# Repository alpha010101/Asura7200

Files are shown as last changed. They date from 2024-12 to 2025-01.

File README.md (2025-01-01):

## ASURA7200

###
ATmega4808を使ったマイコン基板で、NXPのPCA9685という16chのPWM制御ICの評価を目的としている。用途はLEDの明るさ制御で、PWMが4096階調であることから、よくある256階調などよりも滑らかな明るさの変化が実現できる。また、PWMのクロックが高速であるためにチラつきが無い。このあたり、実際に見てみれば誰にでも分かるが、256階調や低速クロックによるチラつきのあるものとは光の質が全く違う。

同様のことを旧基板ではTIのTLC5940というICで行っていた。機能としてはPCA9685とそれほど変わらないが、TLC5940がSPIに似た制御であるのに対し、PCA9685は完全に  I2Cでの制御となっており、他のICと信号線を使い回せる点が有り難い。それ以外もPCA9685の方が応用の範囲が広いように思われる。

電源はXHコネクタから入れており、7V~35Vの入力を受け付け、それをMC7805レギュレータで5V/1Aの内部電源に落としている。これは入力に12Vや24Vを入れてLEDの駆動に使うことを前提にしているためである。このように5Vを超える電圧でLEDを駆動するために、LEDのドライバには東芝のDMOS-SINKドライバTBD62083を使用している。  
  
この他にオマケとしてRTC用としてDS1307を載せており、これもI2C制御になる。バッテリーソケットはこれのバックアップ用。

スカスカの基板に見えると思うが、旧基板にサイズやコネクタを合わせたためにこうなった。ゼロから作るならもう少しコンパクトなコネクタを使うと思う。ミスったのは、通電を示すLEDを付けなかったことで、旧基板がそうだったので忘れていた。基板上に1個のってるLEDはNeo-pixelのRGB LEDで、ソフトウェアの動作ステージなどを示す目的で設けられている。

ソフトウェア開発はArduinoを想定。ATmega4808はArduino-nano-everyなどでも使われており、それほどマイナーでは無いものの、流通しているライブラリではATmega4808を想定していない（デフォルトがATmega328)ものもかなりあり注意が必要だった。例としてはArduinoのSketchで用意された割り込みではなく、直接割り込みを操作しているようなライブラリではATmega328とATmega4808の割り込みの仕組みが違うために動作しないものがあった。  
  
設計当初は意識していなかったのだが、ATmega4808は3系統のUARTを使用可能でその後これに助けられたことがあった。

SchematicとPCB\_LayoutはAutodesk-Eagleの無償版を使用し、elecrowで製造することを想定したガーバーを作成している

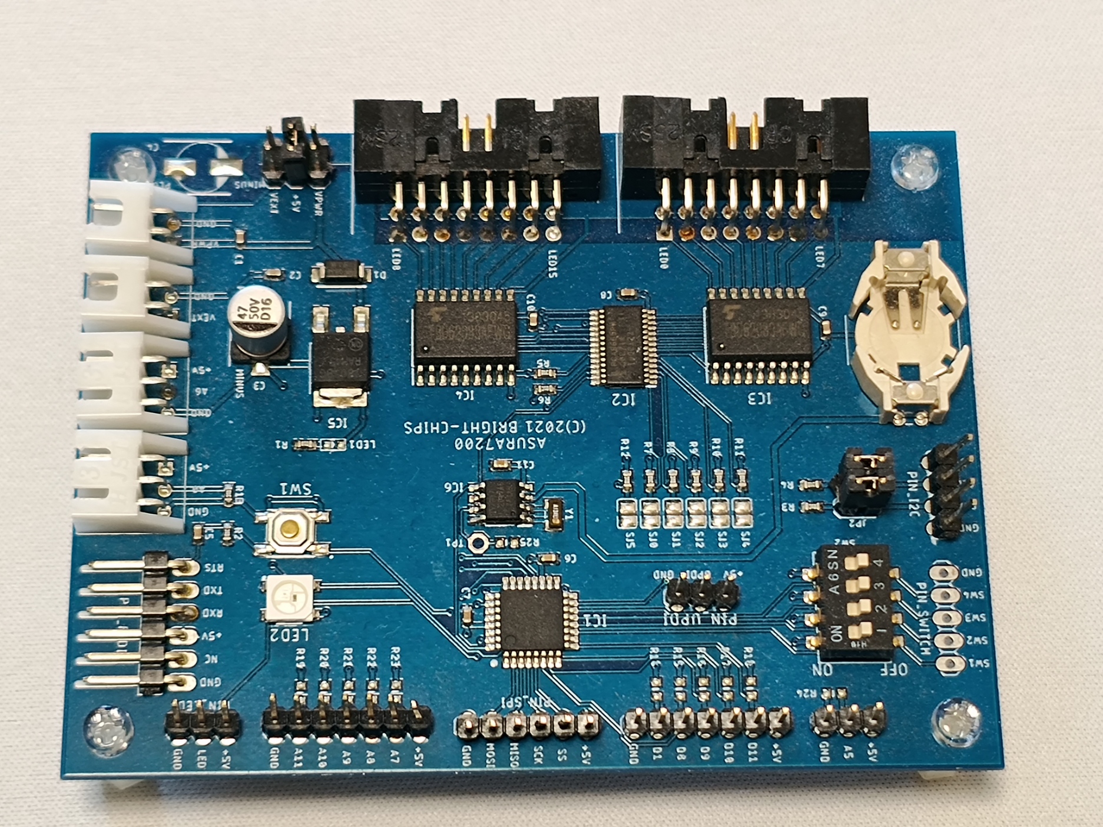
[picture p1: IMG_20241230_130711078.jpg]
ASURA7200


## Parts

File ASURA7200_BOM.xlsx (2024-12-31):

Part_name_on_PCB | Device | Qty | Package | Description | MANUFACTURER_NAME | MANUFACTURER_PART_NUMBER | Source | MOUSER_PART_NUMBER | MOUSER_PRICE-STOCK
C1,C8,C9,C10 | CC0603KRX7R9BB104 | 4 | CAPC1608X90N | CAP, 0603 100nF +/-10% 50V | YAGEO (PHYCOMP) | CC0603KRX7R9BB104 | Elecrow
C2,C5,C6,C7,C11 | CC0603KRX7R8BB105 | 5 | CAPC1608X90N | CAP, 1uF 25V, 0603 | YAGEO (PHYCOMP) | CC0603KRX7R8BB105 | Elecrow
C3 | DV470M050E077ETR | 1 | CAPAE660X800N | CAP, 47uF, SMD 50V | CapXon | DV470M050E077ETR | Elecrow/Shenzhen
C4 | DV470M050E077ETR | 0 | CAPAE660X800N | No need to assemble | CapXon | DV470M050E077ETR | Elecrow/Shenzhen
D1 | S1M | 1 | DIOM5227X270N | RECTIFIER DIODE, STANDARD, 1A, 1000V, SMD | ON Semiconductor | S1M | Elecrow/Shenzhen
IC1 | ATMEGA4808-AU | 1 | QFP80P900X900X120-32N | 8-bit Microcontrollers - MCU 20MHz, 48KB, TQFP | Microchip | ATMEGA4808-AU | mouser | 556-ATMEGA4808-AU | https://www.mouser.co.uk/ProductDetail/Microchip-Technology-Atmel/ATMEGA4808-AU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
IC2 | PCA9685PW,118 | 1 | SOP65P640X110-28N | LED Display Drivers | NXP | PCA9685PW,118 | mouser | 771-PCA9685PW,118 | https://www.mouser.co.uk/ProductDetail/NXP-Semiconductors/PCA9685PW118?qs=6YAT8rHPFU%252BtfwwKq4nwEQ%3D%3D
IC3,IC4 | TBD62083AFWG,EL | 2 | SOIC127P1032X285-18N | Gate Drivers DMOS Transistor Array 8-CH, 50V/0.5A | Toshiba | TBD62083AFWG,EL | Elecrow/Shenzhen
IC5 | MC7805BDTRKG | 1 | LM317MADTRKG | Linear Voltage Regulators 5V 1A Positive | ON Semiconductor | MC7805BDTRKG | Elecrow/Shenzhen
IC6 | DS1307Z+ | 1 | SOIC127P600X175-8N | DS1307Z+, RTC,I2C, 5V, 8-Pin SOIC | Maxim Integrated | DS1307Z+ | Elecrow/Shenzhen
LED1 | SMD-LED-CLEAR-GREEN(0603) | 1 | LED-0603 | SMD LED, SKU=304090057 | Everlight | 17-215SYGC/S530-E2/TR8 | Elecrow |  | https://media.digikey.com/pdf/Data%20Sheets/Everlight%20PDFs/17-215SYGC_S530-E2_TR8%20_rev3_10-13-18.pdf
LED2 | WS2812B | 1 | WS2812B | Intelligent control LED SMD5050, SKU=304990003 | Worldsemi | WS2812B | Elecrow |  | https://statics3.seeedstudio.com/images/opl/datasheet/304990003.pdf
R1 | RC0603JR-071KL | 1 | RESC1608X55N | RES, THICK FILM, 1K, 5%, 0.1W, 0603 | YAGEO (PHYCOMP) | RC0603JR-071KL | Elecrow
R2~R13,R25 | RC0603JR-0710KL | 13 | RESC1608X55N | RES, THICK FILM, 10K, 5%, 0.1W, 0603 | YAGEO (PHYCOMP) | RC0603JR-0710KL | Elecrow
R14~R24 | RC0603JR-0710KL | 0 | RESC1608X55N | No need to assemble | YAGEO (PHYCOMP) | RC0603JR-0710KL | Elecrow
SW1 | SKQGADE010 | 1 | SKQGAKE010 | Tact switch,SMT,SPST,SPST-NO 50 mA 1.5mm | ALPS | SKQGADE010 | Elecrow
SW2 | A6SN-4104 | 1 | SW_A6SN-4104_OMR | DIP switch | OMRON | A6SN-4104 | mouser | 653-A6SN-4104 | https://www.mouser.jp/ProductDetail/Omron-Electronics/A6SN-4104?qs=hAJFN2R7%2FQxeFzNwqs8GZw%3D%3D
Y1 | FC-135 32.7680KA-A3 | 1 | FC-135 32.7680KA-A3 | Crystals 32.768KHz 20ppm 12.5pF -40C -85C | Epson Timing | FC-135 32.7680KA-A3 | mouser | 732-FC135-32.76KAA3 | https://www.mouser.jp/ProductDetail/Epson-Timing/FC-135-327680KA-A3?qs=l3LL3yk8ONaUpektQ%252BySkw%3D%3D
CON_BR,CON_IRDA | S3B-XH-A(LF)(SN) | 0 |  | No need to assemble | JST
CON_LED1,CON_LED2 | HIF3FC-16PA-2.54DS_71_ | 0 |  | No need to assemble | Hirose
CON_VEXT,CON_VPWR | S2B-XH-A(LF)(SN) | 0 |  | No need to assemble | JST
JP1 | PINHD-2X3 | 0 | 2X03 | No need to assemble
JP2 | PINHD-2X2 | 0 | 2X02 | No need to assemble
PIN_ANA1 ,PIN_LED,PIN_UPDI | PINHD-1X3 | 0 | 1X03 | No need to assemble
PIN_ANA2,PIN_DIGITAL | PINHD-1X7 | 0 | 1X07 | No need to assemble
PIN_FTDI | PINHD-1X6/90 | 0 | 1X06/90 | No need to assemble
PIN_I2C | PINHD-1X4 | 0 | 1X04 | No need to assemble
PIN_SPI | PINHD-1X6 | 0 | 1X06 | No need to assemble
PIN_SWITCH | PINHD-1X5 | 0 | 1X05 | No need to assemble
U1 | HU1225-LF | 0 | HU1225LF | No need to assemble | RENATA
SJ0~SJ5 | SJ | 6 | SJ | SMD solder JUMPER

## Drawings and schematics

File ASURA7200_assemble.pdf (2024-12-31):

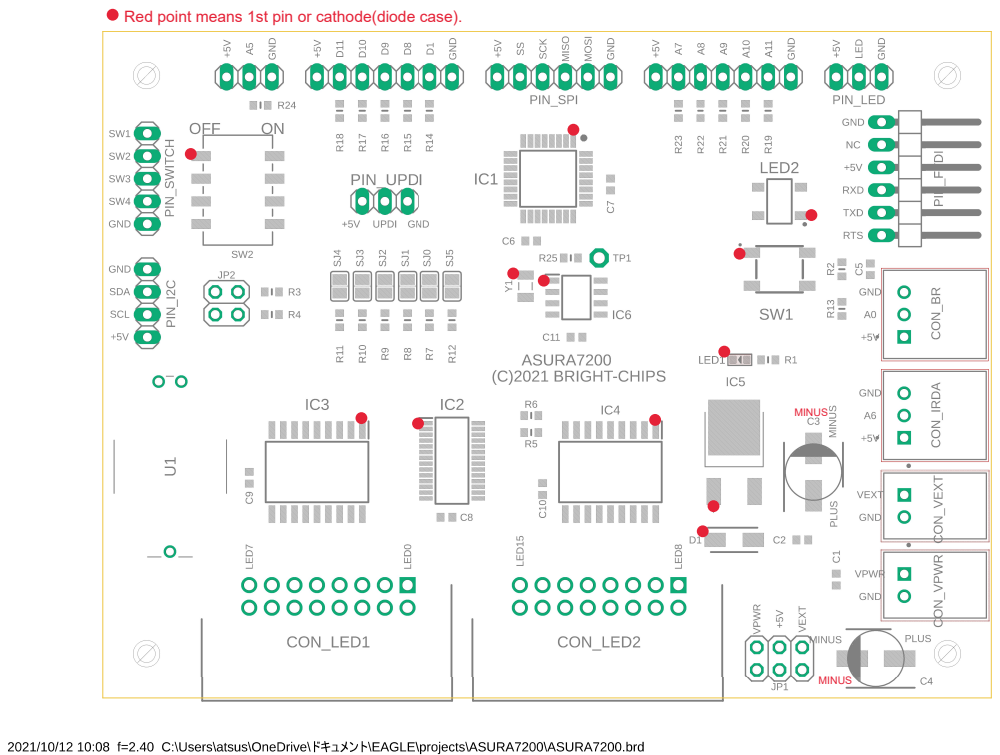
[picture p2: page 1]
MINUS

Red point means 1st pin or cathode(diode case).

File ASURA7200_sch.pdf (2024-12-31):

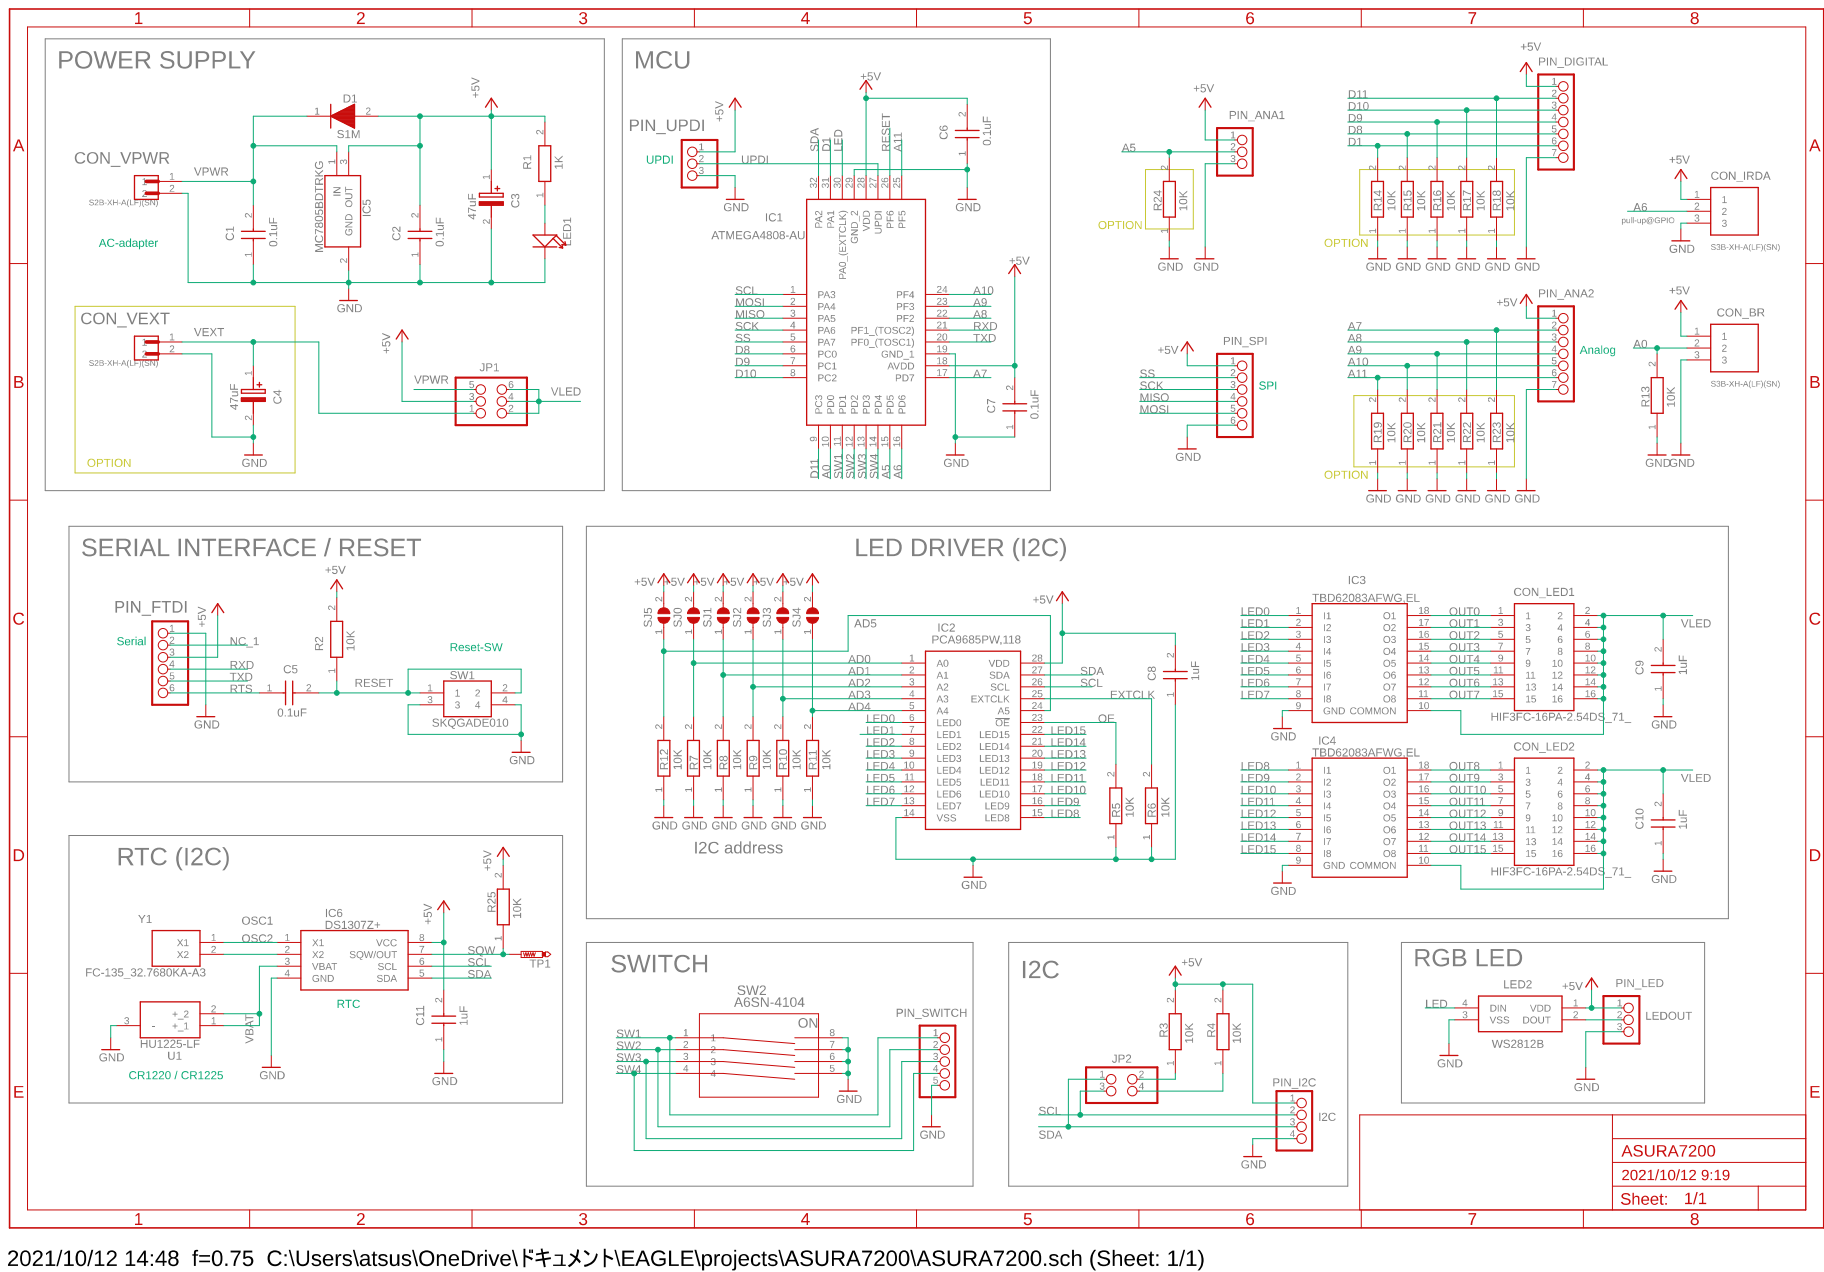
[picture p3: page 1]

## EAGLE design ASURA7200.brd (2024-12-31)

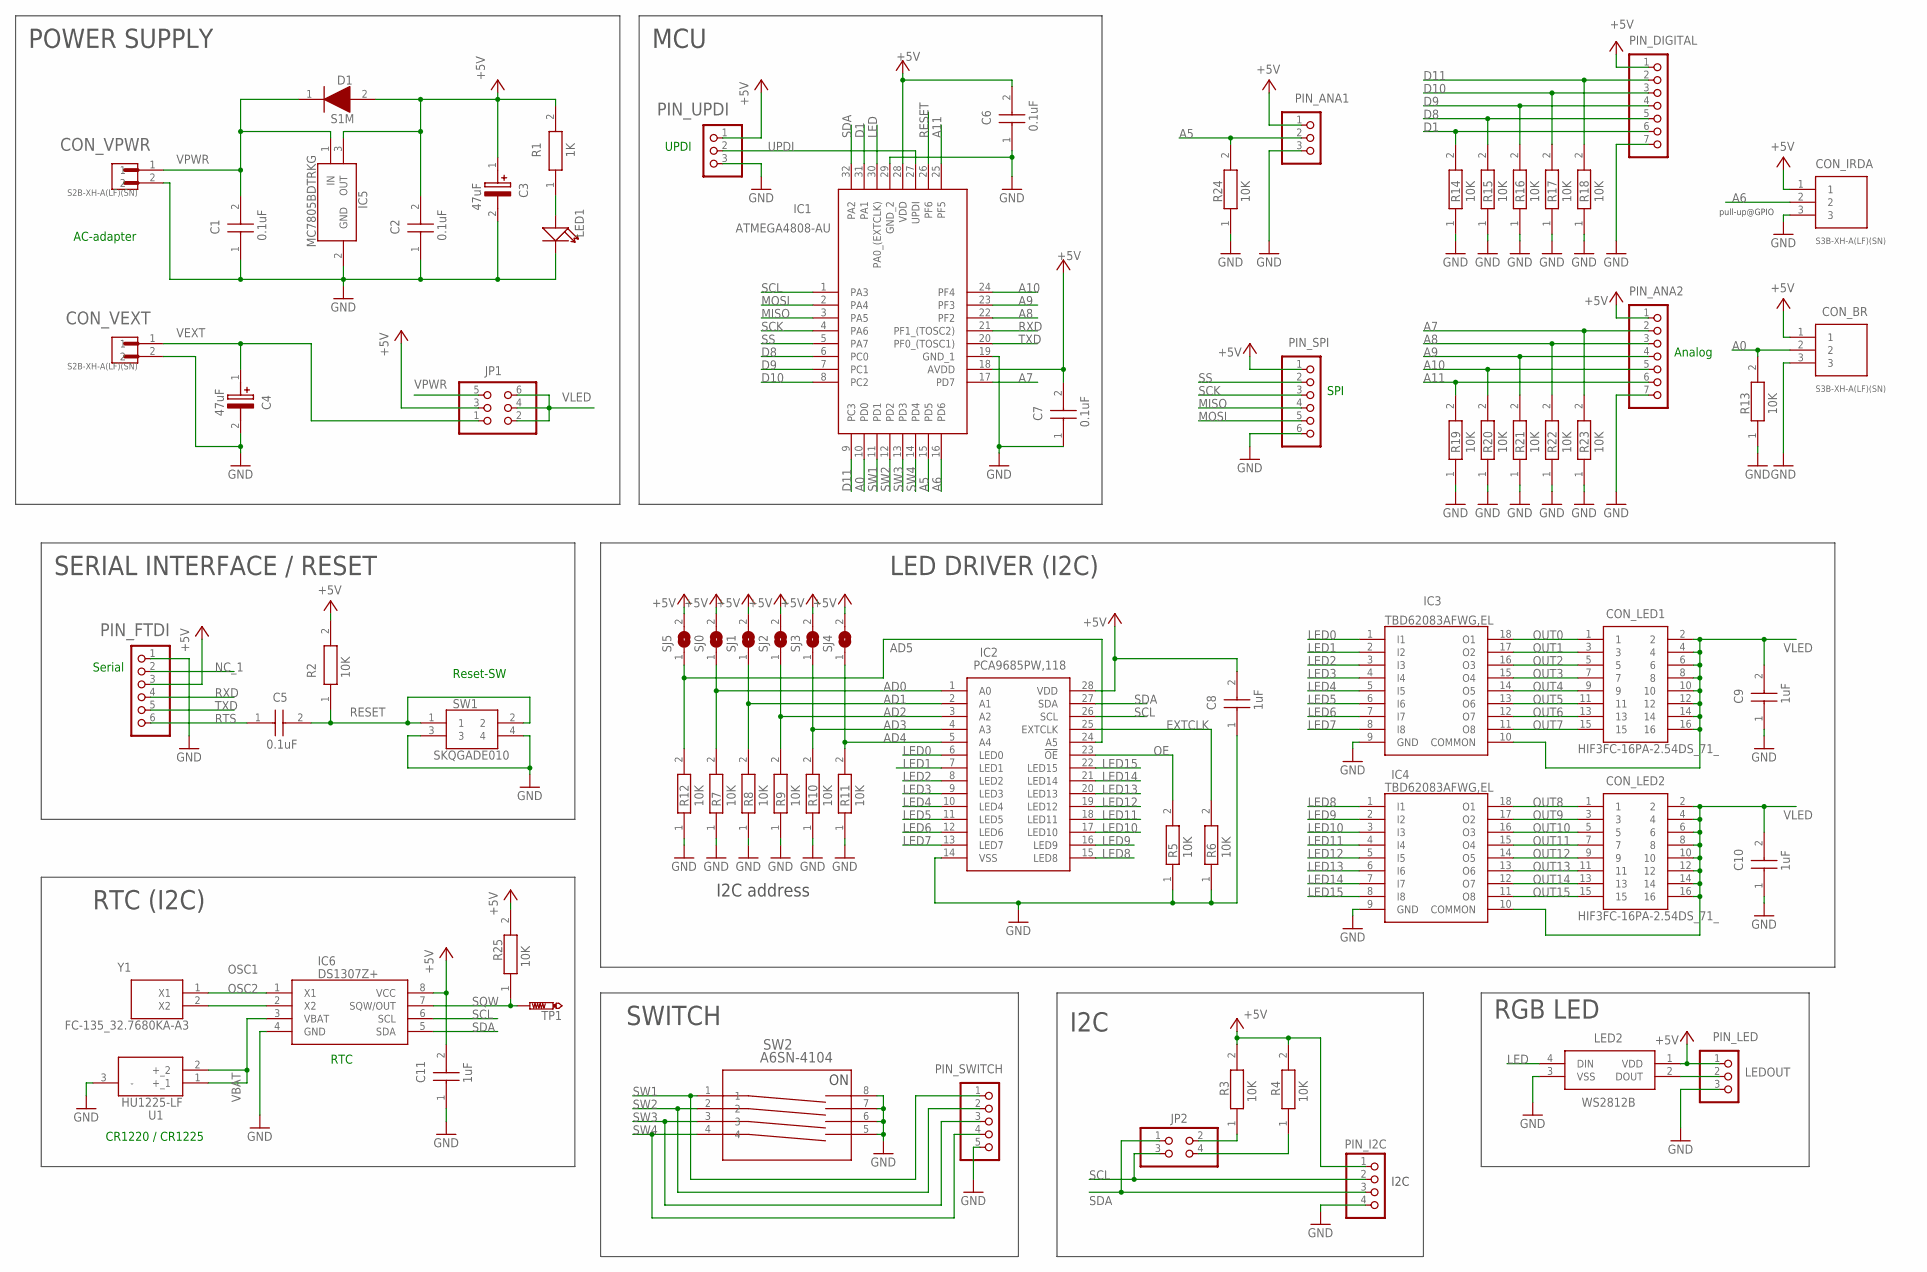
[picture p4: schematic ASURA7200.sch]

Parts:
C1, C8, C9, C10: CC0603KRX7R9BB104; CAPC1608X90N
C2, C5, C6, C7, C11: CC0603KRX7R8BB105; CAPC1608X90N
C3, C4: UUD1H470MCL1GS; CAPAE660X800N
CON_BR: S3B-XH-A(LF)(SN); JST_S3B-XH-A(LF)(SN)
CON_IRDA: S3B-XH-A(LF)(SN); JST_S3B-XH-A(LF)(SN)
CON_LED1, CON_LED2: HIF3FC-16PA-2.54DS_71_; SHDRRA16W69P254X254_2X8_2782X8
CON_VEXT: S2B-XH-A(LF)(SN); JST_S2B-XH-A(LF)(SN)
CON_VPWR: S2B-XH-A(LF)(SN); JST_S2B-XH-A(LF)(SN)
D1: S1M; DIOM5227X270N
IC1: ATMEGA4808-AU; QFP80P900X900X120-32N
IC2: PCA9685PW,118; SOP65P640X110-28N
IC3, IC4: TBD62083AFWG,EL; SOIC127P1032X285-18N
IC5: MC7805BDTRKG; LM317MADTRKG
IC6: DS1307Z+; SOIC127P600X175-8N
JP1: PINHD-2X3; 2X03
JP2: PINHD-2X2; 2X02
LED1: SMD-LED-CLEAR-GREEN(0603); LED-0603
LED2: WS2812B
PIN_ANA1: PINHD-1X3; 1X03
PIN_ANA2: PINHD-1X7; 1X07
PIN_DIGITAL: PINHD-1X7; 1X07
PIN_FTDI: PINHD-1X6/90; 1X06/90
PIN_I2C: PINHD-1X4; 1X04
PIN_LED: PINHD-1X3; 1X03
PIN_SPI: PINHD-1X6; 1X06
PIN_SWITCH: PINHD-1X5; 1X05
PIN_UPDI: PINHD-1X3; 1X03
R1: RC0603JR-071KL; RESC1608X55N
R2, R3, R4, R5, R6, R7, R8, R9, R10, R11, R12, R13, R14, R15, R16, R17, R18, R19, R20, R21, R22, R23, R24, R25: RC0603JR-0710KL; RESC1608X55N
SJ0, SJ1, SJ2, SJ3, SJ4, SJ5: SJ
SW1: SKQGADE010; SKQGAKE010
SW2: A6SN-4104; SW_A6SN-4104_OMR
TP1: PTR1PAD1-13; P1-13
U1: HU1225-LF; HU1225LF
Y1: FC-135_32.7680KA-A3; FC135327680KAA3

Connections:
+5V: C2.2, C3.1 (+), C6.2, C7.2, C8.2, C11.2, CON_BR.1, CON_IRDA.1, D1.2 (A), IC1.18 (AVDD), IC1.28 (VDD), IC2.28 (VDD), IC5.3 (OUT), IC6.8 (VCC), JP1.3, LED2.1 (VDD), PIN_ANA1.1, PIN_ANA2.1, PIN_DIGITAL.1, PIN_FTDI.3, PIN_I2C.1, PIN_LED.1, PIN_SPI.1, PIN_UPDI.1, R1.2, R2.2, R3.2, R4.2, R25.2, SJ0.2, SJ1.2, SJ2.2, SJ3.2, SJ4.2, SJ5.2
A0: CON_BR.2, IC1.10 (PD0), R13.2
A5: IC1.15 (PD5), PIN_ANA1.2, R24.2
A6: CON_IRDA.2, IC1.16 (PD6)
A7: IC1.17 (PD7), PIN_ANA2.2, R23.2
A8: IC1.22 (PF2), PIN_ANA2.3, R22.2
A9: IC1.23 (PF3), PIN_ANA2.4, R21.2
A10: IC1.24 (PF4), PIN_ANA2.5, R20.2
A11: IC1.25 (PF5), PIN_ANA2.6, R19.2
AD0: IC2.1 (A0), R7.2, SJ0.1
AD1: IC2.2 (A1), R8.2, SJ1.1
AD2: IC2.3 (A2), R9.2, SJ2.1
AD3: IC2.4 (A3), R10.2, SJ3.1
AD4: IC2.5 (A4), R11.2, SJ4.1
AD5: IC2.24 (A5), R12.2, SJ5.1
D1: IC1.31 (PA1), PIN_DIGITAL.6, R14.2
D8: IC1.6 (PC0), PIN_DIGITAL.5, R15.2
D9: IC1.7 (PC1), PIN_DIGITAL.4, R16.2
D10: IC1.8 (PC2), PIN_DIGITAL.3, R17.2
D11: IC1.9 (PC3), PIN_DIGITAL.2, R18.2
EXTCLK: IC2.25 (EXTCLK), R6.2
GND: C1.1, C2.1, C3.2 (-), C4.2 (-), C6.1, C7.1, C8.1, C9.1, C10.1, C11.1, CON_BR.3, CON_IRDA.3, CON_VEXT.2, CON_VPWR.2, IC1.19 (GND_1), IC1.29 (GND_2), IC2.14 (VSS), IC3.9 (GND), IC4.9 (GND), IC5.2 (GND), IC6.4 (GND), LED1.-, LED2.3 (VSS), PIN_ANA1.3, PIN_ANA2.7, PIN_DIGITAL.7, PIN_FTDI.1, PIN_I2C.4, PIN_LED.3, PIN_SPI.6, PIN_SWITCH.5, PIN_UPDI.3, R5.1, R6.1, R7.1, R8.1, R9.1, R10.1, R11.1, R12.1, R13.1, R14.1, R15.1, R16.1, R17.1, R18.1, R19.1, R20.1, R21.1, R22.1, R23.1, R24.1, SW1.3, SW1.4, SW2.5, SW2.6, SW2.7, SW2.8, U1.3 (-)
LED: IC1.30 (PA0_(EXTCLK)), LED2.4 (DIN)
LED0: IC2.6 (LED0), IC3.1 (I1)
LED1: IC2.7 (LED1), IC3.2 (I2)
LED2: IC2.8 (LED2), IC3.3 (I3)
LED3: IC2.9 (LED3), IC3.4 (I4)
LED4: IC2.10 (LED4), IC3.5 (I5)
LED5: IC2.11 (LED5), IC3.6 (I6)
LED6: IC2.12 (LED6), IC3.7 (I7)
LED7: IC2.13 (LED7), IC3.8 (I8)
LED8: IC2.15 (LED8), IC4.1 (I1)
LED9: IC2.16 (LED9), IC4.2 (I2)
LED10: IC2.17 (LED10), IC4.3 (I3)
LED11: IC2.18 (LED11), IC4.4 (I4)
LED12: IC2.19 (LED12), IC4.5 (I5)
LED13: IC2.20 (LED13), IC4.6 (I6)
LED14: IC2.21 (LED14), IC4.7 (I7)
LED15: IC2.22 (LED15), IC4.8 (I8)
LEDOUT: LED2.2 (DOUT), PIN_LED.2
LED_IN: LED1.+, R1.1
MISO: IC1.3 (PA5), PIN_SPI.4
MOSI: IC1.2 (PA4), PIN_SPI.5
NC_1: PIN_FTDI.2
OE: IC2.23 (!OE), R5.2
OSC1: IC6.1 (X1), Y1.1 (X1)
OSC2: IC6.2 (X2), Y1.2 (X2)
OUT0: CON_LED1.1, IC3.18 (O1)
OUT1: CON_LED1.3, IC3.17 (O2)
OUT2: CON_LED1.5, IC3.16 (O3)
OUT3: CON_LED1.7, IC3.15 (O4)
OUT4: CON_LED1.9, IC3.14 (O5)
OUT5: CON_LED1.11, IC3.13 (O6)
OUT6: CON_LED1.13, IC3.12 (O7)
OUT7: CON_LED1.15, IC3.11 (O8)
OUT8: CON_LED2.1, IC4.18 (O1)
OUT9: CON_LED2.3, IC4.17 (O2)
OUT10: CON_LED2.5, IC4.16 (O3)
OUT11: CON_LED2.7, IC4.15 (O4)
OUT12: CON_LED2.9, IC4.14 (O5)
OUT13: CON_LED2.11, IC4.13 (O6)
OUT14: CON_LED2.13, IC4.12 (O7)
OUT15: CON_LED2.15, IC4.11 (O8)
RESET: C5.2, IC1.26 (PF6), R2.1, SW1.1, SW1.2
RTS: C5.1, PIN_FTDI.6
RXD: IC1.21 (PF1_(TOSC2)), PIN_FTDI.4
SCK: IC1.4 (PA6), PIN_SPI.3
SCL: IC1.1 (PA3), IC2.26 (SCL), IC6.6 (SCL), JP2.3, PIN_I2C.2
SCL_1: JP2.4, R4.1
SDA: IC1.32 (PA2), IC2.27 (SDA), IC6.5 (SDA), JP2.1, PIN_I2C.3
SDA_1: JP2.2, R3.1
SQW: IC6.7 (SQW/OUT), R25.1, TP1.TP
SS: IC1.5 (PA7), PIN_SPI.2
SW1: IC1.11 (PD1), PIN_SWITCH.1, SW2.1
SW2: IC1.12 (PD2), PIN_SWITCH.2, SW2.2
SW3: IC1.13 (PD3), PIN_SWITCH.3, SW2.3
SW4: IC1.14 (PD4), PIN_SWITCH.4, SW2.4
TXD: IC1.20 (PF0_(TOSC1)), PIN_FTDI.5
UPDI: IC1.27 (UPDI), PIN_UPDI.2
VBAT: IC6.3 (VBAT), U1.1 (+_1), U1.2 (+_2)
VEXT: C4.1 (+), CON_VEXT.1, JP1.1
VLED: C9.2, C10.2, CON_LED1.2, CON_LED1.4, CON_LED1.6, CON_LED1.8, CON_LED1.10, CON_LED1.12, CON_LED1.14, CON_LED1.16, CON_LED2.2, CON_LED2.4, CON_LED2.6, CON_LED2.8, CON_LED2.10, CON_LED2.12, CON_LED2.14, CON_LED2.16, IC3.10 (COMMON), IC4.10 (COMMON), JP1.2, JP1.4, JP1.6
VPWR: C1.2, CON_VPWR.1, D1.1 (K), IC5.1 (IN), JP1.5

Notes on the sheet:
CR1220 / CR1225
Reset-SW
RTC
UPDI
Serial
AC-adapter
SPI
Analog
RTC (I2C)
SERIAL INTERFACE / RESET
POWER SUPPLY
MCU
SWITCH
pull-up@GPIO
I2C
LED DRIVER (I2C)
I2C address
RGB LED

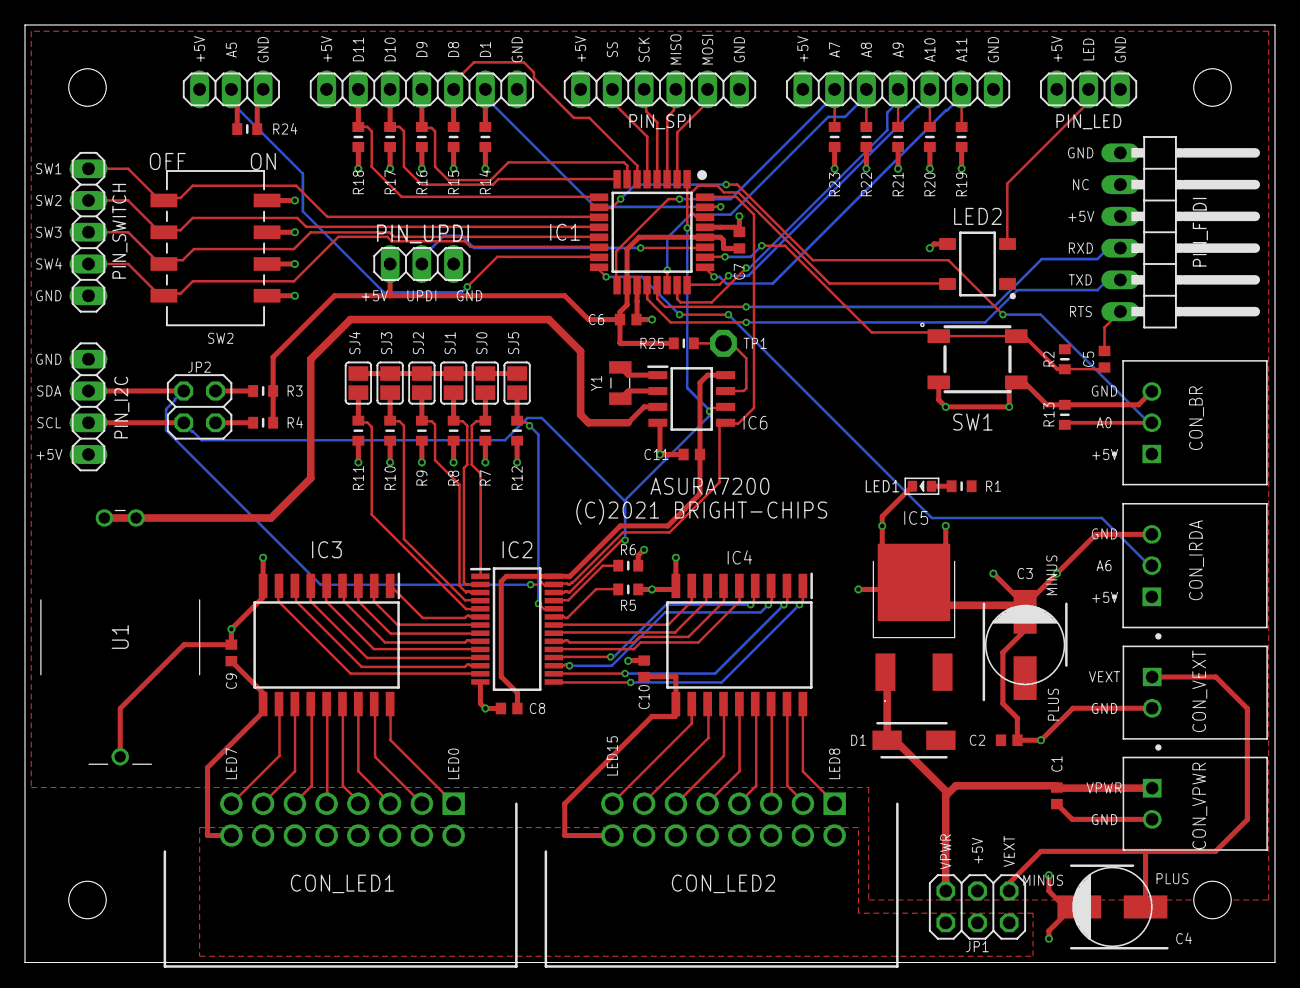
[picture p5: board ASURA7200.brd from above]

Board: 2 copper layers, 100.0 x 75.0 mm, 73 parts (0 on the bottom side), 82 nets.

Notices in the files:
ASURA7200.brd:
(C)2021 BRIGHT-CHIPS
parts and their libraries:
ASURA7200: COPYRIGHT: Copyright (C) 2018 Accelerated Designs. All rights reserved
